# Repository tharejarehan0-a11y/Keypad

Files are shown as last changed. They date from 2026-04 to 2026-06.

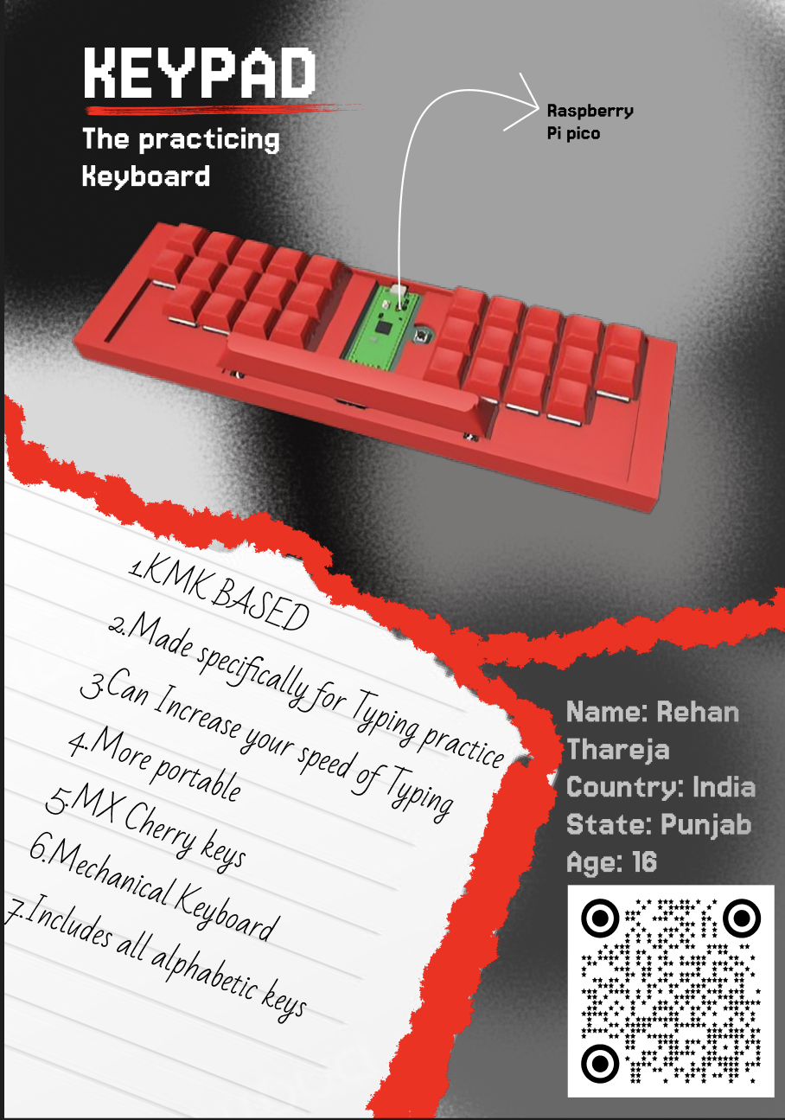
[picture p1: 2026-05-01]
zinepage.png

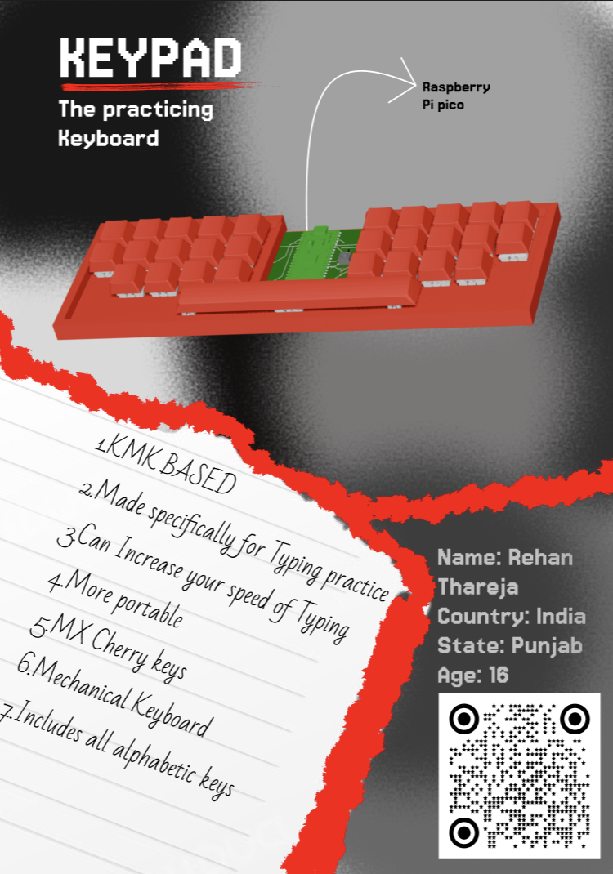
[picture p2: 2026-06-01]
Media/Zinepage.png

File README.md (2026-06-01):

# Keypad
<br>



<br>

# **Keyboard for Beginners**
(_It is Keypad a keyboard designed specifically to make learning touch typing efficient and more easy for beginners_)

<br>

<p align="center">
Screenshot 2026-06-01 at 6 14 18 PM
</p>

<br>

# **Story Behind it/Motivation**
When I started my computer journey I started learning how to do typing fast (_touch typing_). I was made to type only alphabets in the whole course some or the other way for me there was like no use of other keys similarly for many people other keys are just useless when they want to learn typing or practice it **and it is specifically designed for it**

# **Key takeaways**

1. Best for people starting touch typing
2. More portable if only learning to type
3. Mechanical keyboard with MX Cherry Keys
4. Can be customized using the firmware unlike ordinary keyboards

# **Schematics**

# Matrix
<br>
Screenshot 2026-04-22 at 7 55 31 PM
<br><br>

**These keys are layed in a matrix of rows and columns. There are 10 columns and 4 rows in the matrix. All the intersection of the rows and columns constitute a key here. The microconttroller that will be attached to these will detect low currect at the key you will press and will have already the columns and rows assigned in the firmware that let it know where the key to detect is. I have attached global labels of rows and columns which can be attached to the microcontroller and help the schematics look a lot cleaner**

<br><br>
# Keys
<br>
Screenshot 2026-04-22 at 7 51 36 PM

<br><br>
**The key composes of a keyswitch and a diode these help the microcontroller help detect the lower currect in the matrix of rows and columns**

<br><br>
# Microcontroller
<br>
Screenshot 2026-04-22 at 7 51 54 PM

<br><br>
**As a microcontroller we are using the raspberry pi pico which has 22 gpio pins the net lablels or the global net labels are attached to these pins only. The ADC_VREF pin is the analog to digital converter the 3.3v is fed into this pin but has lot of noise that is why we add a capatior of 100nF here. Then we have the 3v3 pin and the run pin . The run pin is connected to a sw_push button with one end of the push button connected to gnd and other end free and the 3v3 pin is essentially the pin that gives out the the 3v3 current it has two capacitors parallely of 100nF and 10µF to reduce the noise you can check out the design at mech_keyboard.kicad_sch**

<br><br>

# **PCB Design**
<br>
Screenshot 2026-04-22 at 8 22 37 PM
<br>

**This is the PCB Design of the keyboard having the footprints of keys of MX_Cherry , The Raspberry pi pico, resistors_smd_do35, sw_push_button and capacitors. There are also mounting holes on the pcb for the screws to fit in . We will be using the m2 screws having dimensions 2mm * 6mm and 2mm * 8mm for it . The routing follows the pattern that the capacitors , sw_push and resistors are done in the front chopper layer and the columns in the back chopper layer but there are vias also present in the pcb which make it hetrogeneous.<br><br>We have used to grind one is 19.05mm and other is 2.3813mm. the first was used for the keys which were moved by reference to it's upper right corner and the second was used for resistors which were moved without any resistors. You can check out the design in mech_Keyboard.kicad_pcb**

# **CAD**
<br>

Screenshot 2026-04-22 at 8 37 48 PM
<br>

**Go to https://www.keyboard-layout-editor.com/ to design a keyboard here we designed it complementing to our pcb and schematics paste this in the raw data tab of the site** 

<br>
<br>

```
  [{ "a": 7 }, "", "", "", "", "", { "x": 3 }, "", "", "", "", ""],
  ["", "", "", "", "", { "x": 3 }, "", "", "", "", ""],
  [{ "x": 1 }, "", "", "", "", { "x": 3 }, "", "", "", ""],
  [{ "x": 3, "w": 7 }, ""]
```

<br>

**then go to https://swillkb.com/ and paste the either the raw data of your design under the raw data tab or paste this onto the website u will get a dxf file which you can also take from the files here**

**Note: I have made some changes in the sketch according to my design you can find those sketches in 3D_Models >> DXF**

# Onshape

<br>
Screenshot 2026-05-31 at 7 18 23 PM

<br>

**Done everything in Onshape you can see all the files related to it go to 3D_Models >> STEP and if you want to see the sketches that will be in 3D_Models >> DXF and the link to onshape is https://cad.onshape.com/documents/34256bf3e585af5c7248ec84/w/d1b125939af1c93ac5709ce3/e/966044b3990b03ffc888e75f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 this you can have a look at it**

<br>

# **firmware**

<br>

Screenshot 2026-04-23 at 7 25 21 PM

<br>

**The firmware is written in Circuit python and has KMK library used to program the keyboard the keymap array is used to assign the keys to the intersection and the rows and columns are denoted by keyboard.row_pins and keyboard.col_pins and we have a name function which loads the code onto the keyboard.**

<br>

# **Components**

1. **Raspberry pi pico**
2. **MX Cherry 1.00u Keys and Keycaps**
3. **MX Cherry 7.00u Keycap and stablizer**
4. **PCB**
5. **DO-35 Resistors**
6. **SMD C_0603_1608Metric Capacitors**
7. **SW_Push Button**
8. **M2 2mm*6mm screws**

<br>

# **BOM**
**Sidenote for reviewers**
_(There is a chance that ktron.in does not accept the hcb money if it happens then i will pay my self)_

| #  | Company | Part | Quantity | Price  | Link |
|----|---|---|---|---|---|
| 1  | JLCPCB | PCB | 1 | 12.25$ | https://www.jlcpcb.com | |
| 2  | Robocraze | Raspberry Pi Pico | 1 | ₹400 | https://robocraze.com/products/raspberry-pi-pico?_pos=2&_sid=2e551ee8b&_ss=r |
| 3  | Robocraze | Male Headers (40x1 pin 2.54mm pitch) | 2 | ₹20 | https://robocraze.com/products/40x1-pin-2-54mm-pitch-male-berg-strip?_pos=11&_sid=5a10e633c&_ss=r |
| 4  | robu.in | 1N4148 Diodes | 30 | ₹180 | https://robu.in/product/1n4148-t50a-onsemi-100v-1v10ma-4ns-200ma-do-35-switching-diodes-rohs |
| 5  | KTRON | SMD 0603 Capacitors 100nF | 25 | ₹20 | https://www.ktron.in/product/100nf-50v-104-mlcc-0603/?v=2978dbfa7f71 |
| 6  | robu.in | SMD 0603 Capacitors 10uF | 5 | ₹20 | https://robu.in/product/10uf-10000nf-50v-capacitor-0603-smd-package-pack-of-5 |
| 7  | Stackskb.com | MX Cherry Keyswitches | 45 | ₹1200 | https://stackskb.com/store/akko-botany-switch-pack-of-45/ |
| 8  | Curiosity Caps | MX Cherry Keycaps | 130+  | ₹2500 | http://curiositycaps.in/products/manga-theme-cherry-pbt-keycaps?variant=50211931226393 |
| 9  | Printing Legion India (via HackClub) | Case | 1 | $2 | https://hackclub.com |
| 10 | OnlyScrews | M2x6mm Screws | 25 | ₹105 | https://onlyscrews.in/products/m2-x-6mm-phillips-round-head-laptop-screw?variant=49369266192697 |
| 11 | OnlyScrews | M2x8mm Screws | 25 | ₹110 | https://onlyscrews.in/products/m2-x-8mm-phillips-round-head-laptop-screw-1?variant=49693360423225 |
| 12 | OnlyScrews | M2 Nuts | 25 | ₹150 | https://onlyscrews.in/products/m2-nyloc-nuts-ss304-dia-2mm?variant=50164298645817 |
| 13 | Stackskb.com | Stabilizers | 4+1 | ₹1595 | https://stackskb.com/store/durock-clear-screw-in-stabilizers-v2/ |
| 14 | Robocraze | SW_Push Buttons | 25 | ₹25 | https://robocraze.com/products/4-pin-push-button-tactile-switch-12x12x15mm-pack-of-5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 |
| 15 | Shipping&Taxes | N/A | All | ₹700+39$ | N/A |

<br>

# **files**

<br>

1. **Readme.md** : explanation of all the project <br>
2. **Kicad** : All the Kicad related files <br> 
3. **Production Files** : Contains all the fabrication files used in the pcb manufacturing process <br>
4. **firmware** : This contains the firmware for the keyboard to be used <br>
5. **3D_Models*** : All the assets needed for 3D printing and all the sketches and 3D Models <br>
6. **Assets_Kicad** : All the assets needed for the schematics and pcb design including the 3d models, footprints, schematic symbols <br>
7. **Zinepage.png** : has the A5 Design for the fallout zine <br>

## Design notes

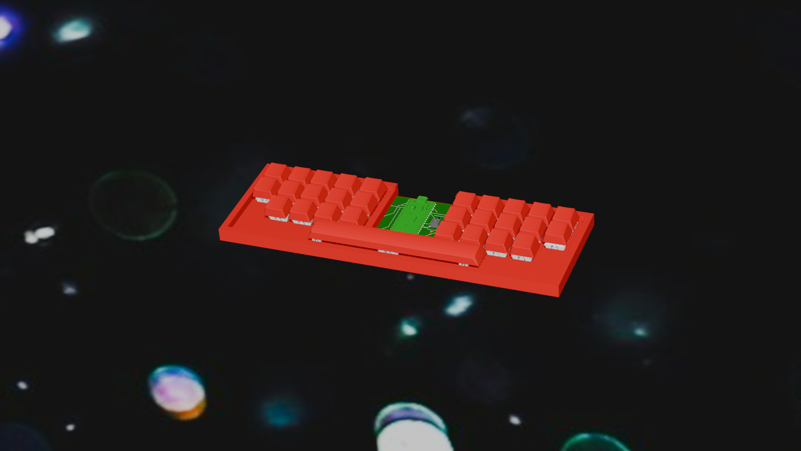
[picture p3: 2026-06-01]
Media/Untitled.png

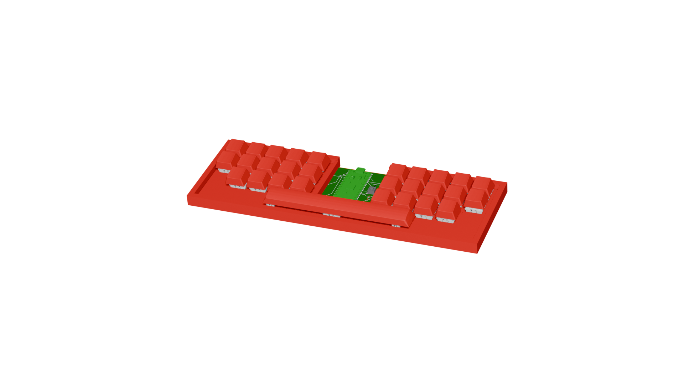
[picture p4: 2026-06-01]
Media/transparent.png

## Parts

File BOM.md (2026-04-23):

# Bill of Materials (BOM)

> Table 1 — Components for the project

| # | Company | Part | Price | Qty | Link |
|---|---|---|---:|:---:|---|
| 1 | PCBWay | PCB | $82.35 | 1 | [Order](https://www.pcbway.com/QuickOrderOnline.aspx) |
| 2 | Robocraze | Raspberry Pi Pico | ₹450.00 | 1 | [Order](https://robocraze.com/products/raspberry-pi-pico?_pos=2&_sid=2e551ee8b&_ss=r) |
| 3 | Robocraze | Male Headers (40×1 pin, 2.54mm pitch) | ₹12.00 | 2 | [Order](https://robocraze.com/products/40x1-pin-2-54mm-pitch-male-berg-strip?_pos=11&_sid=5a10e633c&_ss=r) |
| 4 | robu.in | 1N4148 Diodes | ₹180.00 | 30 | [Order](https://robu.in/product/1n4148-t50a-onsemi-100v-1v10ma-4ns-200ma-do-35-switching-diodes-rohs) |
| 5 | KTRON | SMD 0603 Capacitors 100nF | ₹100.00 | 25 | [Order](https://www.ktron.in/product/100nf-50v-104-mlcc-0603/?v=2978dbfa7f71) |
| 6 | robu.in | SMD 0603 Capacitors 10µF | ₹4.00 | 1 | [Order](https://robu.in/product/10uf-10000nf-50v-capacitor-0603-smd-package-pack-of-5) |
| 7 | Stackskb.com | MX Cherry Keyswitches (Akko Botany) | ₹1,200.00 | 45 | [Order](https://stackskb.com/store/akko-botany-switch-pack-of-45/) |
| 8 | Curiosity Caps | MX Cherry Keycaps (Manga Theme PBT) | ₹2,500.00 | 130 | [Order](http://curiositycaps.in/products/manga-theme-cherry-pbt-keycaps?variant=50211931226393) |
| 9 | Printing Legion India *(via HackClub)* | Case | $1.30 | 1 | [@speedhawks on Hackclub](https://hackclub.com) |
| 10 | OnlyScrews | M2*6mm screws | ₹105 | 25 | [Order](https://onlyscrews.in/products/m2-x-6mm-phillips-round-head-laptop-screw?variant=49369266192697) |
| 11 | OnlyScrews | M2*8mm screws | ₹110 | 25 | [Order](https://onlyscrews.in/products/m2-x-8mm-phillips-round-head-laptop-screw-1?variant=49693360423225) |
| 12 | OnlyScrews | M2 nuts | ₹105 | 25 | [Order](https://onlyscrews.in/products/m2-nyloc-nuts-ss304-dia-2mm?variant=50164298645817) |
| 13 | OnlyScrews | Shipping & Tax | ₹126 | N/A | [Order](https://onlyscrews.in/)

---

> **Note:** Prices marked in ₹ are in Indian Rupees; prices marked in $ are in US Dollars.

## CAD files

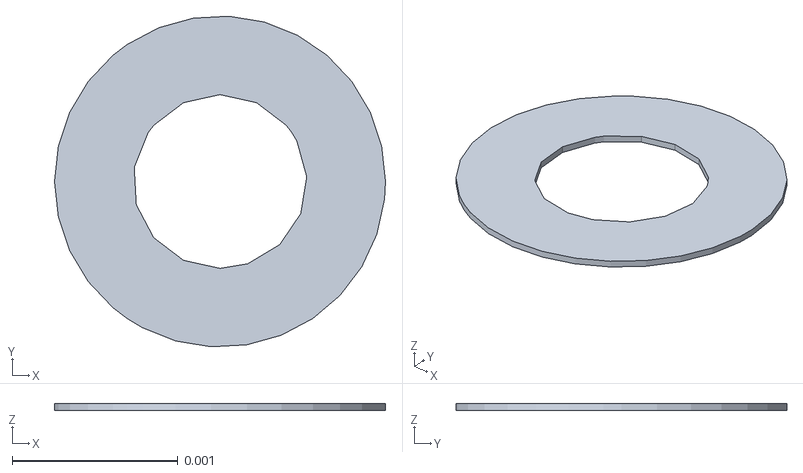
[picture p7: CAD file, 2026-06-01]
3D_Models/STL/assembly/Assembly_Components/Assembly 1 - mech_Keyboard_pad (144).stl
0.002 x 0.002 x 4e-05

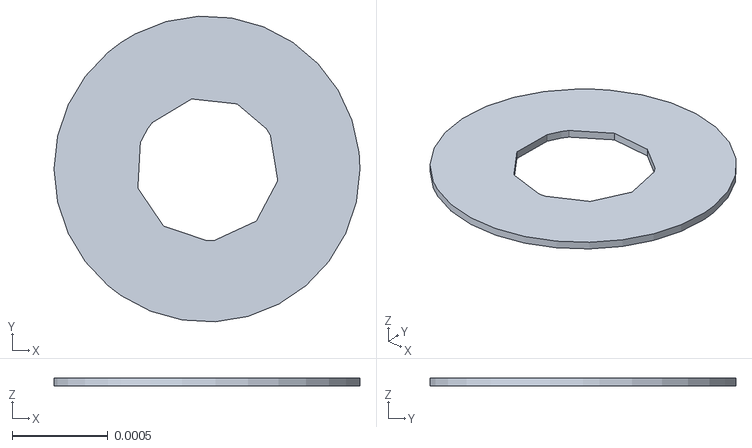
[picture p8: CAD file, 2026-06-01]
3D_Models/STL/assembly/Assembly_Components/Assembly 1 - mech_Keyboard_pad (264).stl
0.0016 x 0.0016 x 4e-05

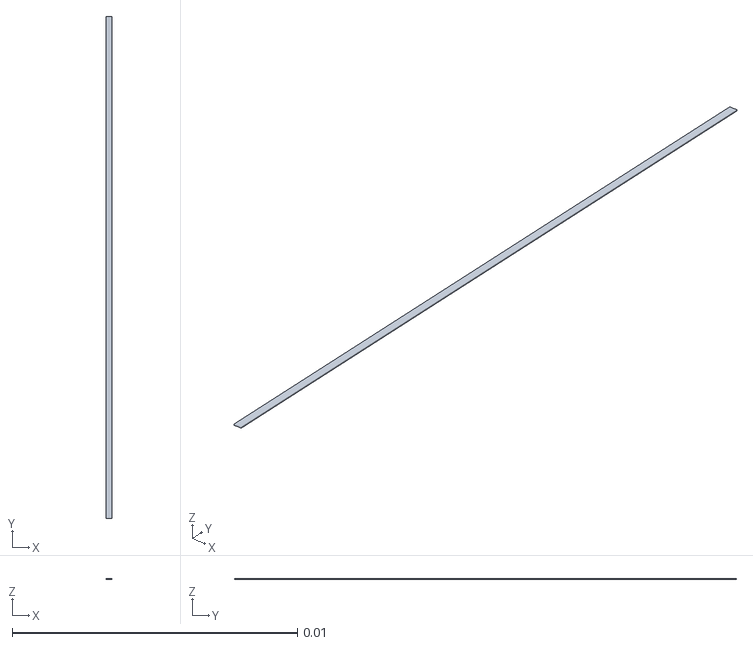
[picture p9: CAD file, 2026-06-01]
3D_Models/STL/assembly/Assembly_Components/Assembly 1 - mech_Keyboard_copper (69).stl
0.000198 x 0.0176 x 3.5e-05

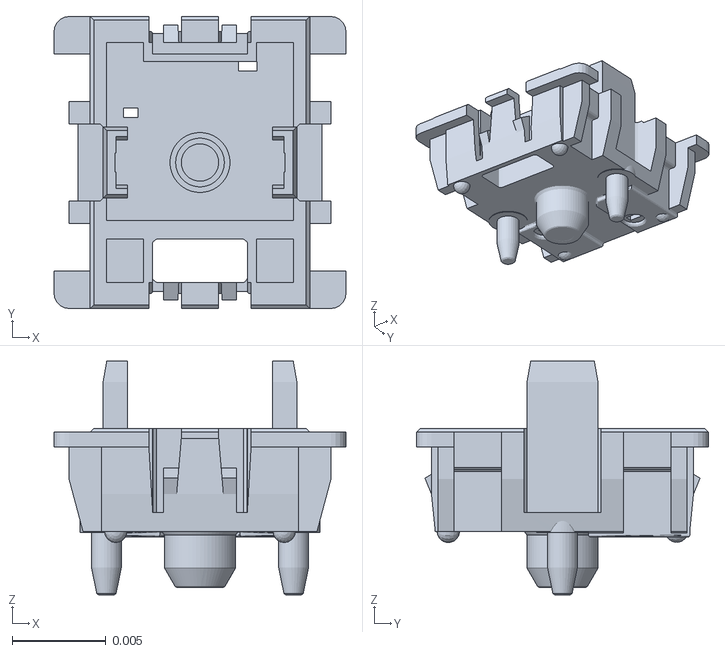
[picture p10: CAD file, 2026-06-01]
3D_Models/STL/assembly/Assembly_Components/Assembly 1 - MX_PCB_28.stl
0.0156 x 0.0156 x 0.0125

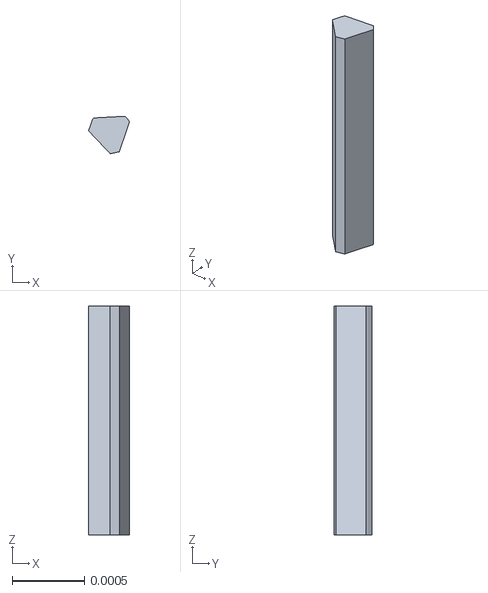
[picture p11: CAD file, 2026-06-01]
3D_Models/STL/assembly/Assembly_Components/Assembly 1 - mech_Keyboard_via (23).stl
0.000282 x 0.000259 x 0.00158

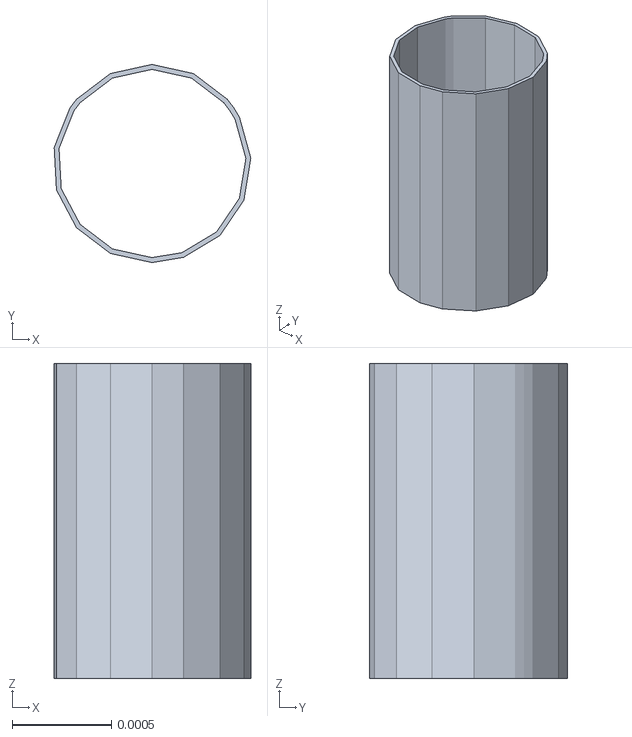
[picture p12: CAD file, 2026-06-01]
3D_Models/STL/assembly/Assembly_Components/Assembly 1 - mech_Keyboard_pad (78).stl
0.000993 x 0.001 x 0.00159

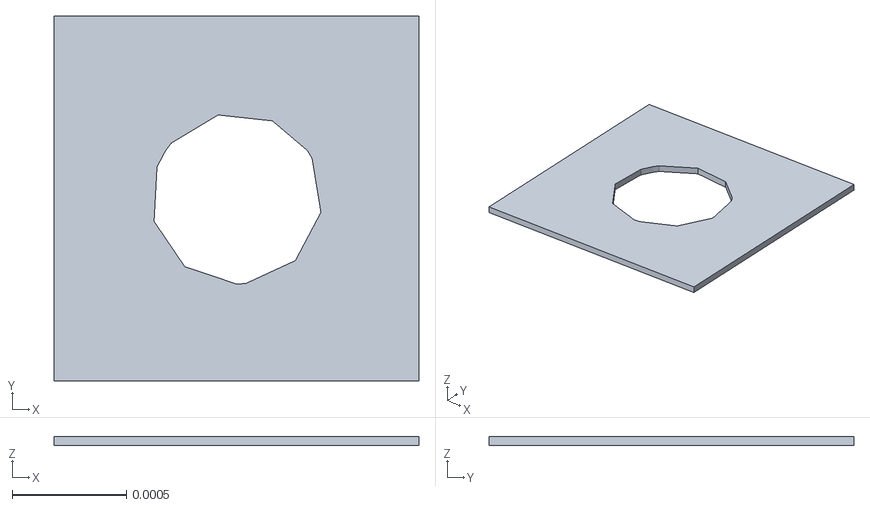
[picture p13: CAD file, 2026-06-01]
3D_Models/STL/assembly/Assembly_Components/Assembly 1 - mech_Keyboard_pad (328).stl
0.0016 x 0.0016 x 4e-05

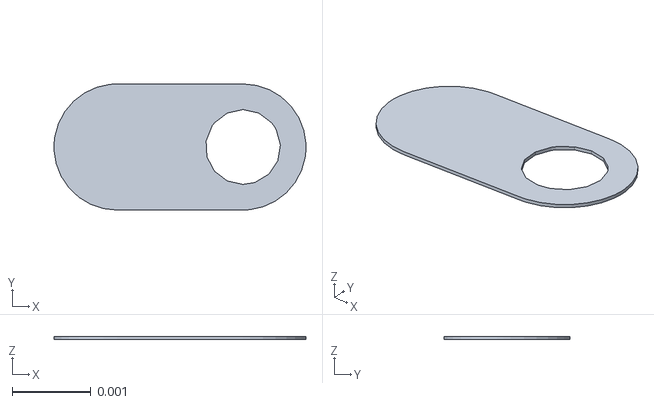
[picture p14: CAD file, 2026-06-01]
3D_Models/STL/assembly/Assembly_Components/Assembly 1 - mech_Keyboard_pad (418).stl
0.0032 x 0.0016 x 4e-05

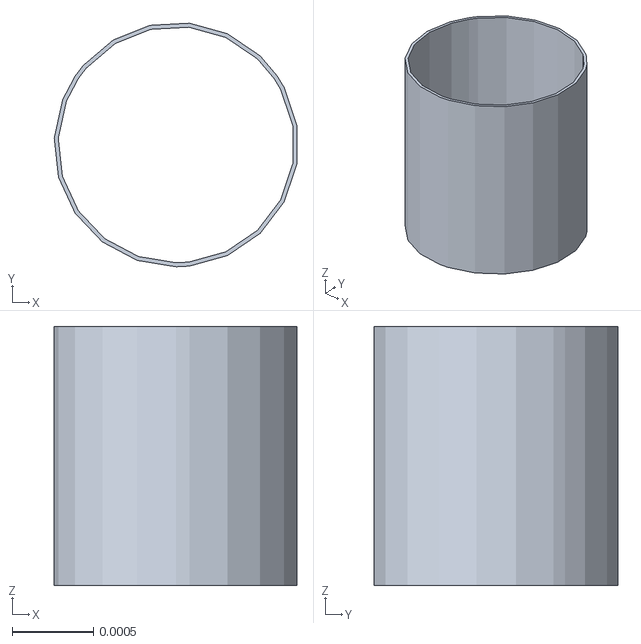
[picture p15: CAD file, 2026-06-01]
3D_Models/STL/assembly/Assembly_Components/Assembly 1 - mech_Keyboard_pad (217).stl
0.00149 x 0.0015 x 0.00159

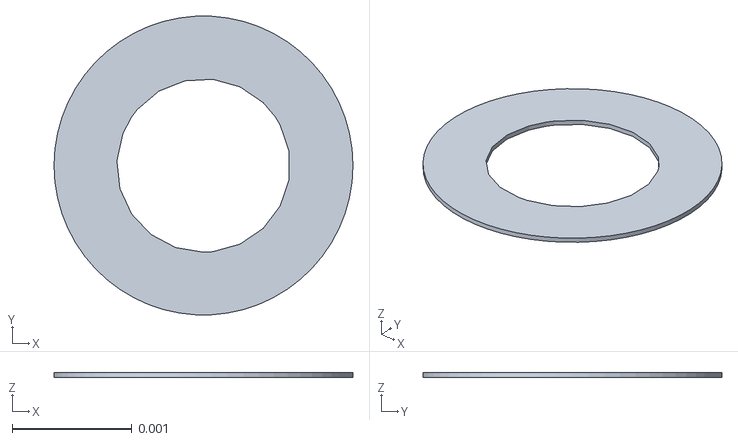
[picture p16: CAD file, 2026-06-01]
3D_Models/STL/assembly/Assembly_Components/Assembly 1 - mech_Keyboard_pad (147).stl
0.0025 x 0.0025 x 4e-05

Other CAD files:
3D_Models/STL/assembly/Assembly_Components/Assembly 1 - mech_Keyboard_pad (337).stl
3D_Models/STL/assembly/Assembly_Components/Assembly 1 - mech_Keyboard_via (24).stl
3D_Models/STL/assembly/Assembly_Components/Assembly 1 - mech_Keyboard_copper (25).stl
3D_Models/STL/assembly/Assembly_Components/Assembly 1 - mech_Keyboard_pad (60).stl
3D_Models/STL/assembly/Assembly_Components/Assembly 1 - mech_Keyboard_pad (496).stl
3D_Models/STL/assembly/Assembly_Components/Assembly 1 - mech_Keyboard_pad (363).stl
3D_Models/STL/assembly/Assembly_Components/Assembly 1 - mech_Keyboard_pad (62).stl
3D_Models/STL/assembly/Assembly_Components/Assembly 1 - mech_Keyboard_pad (204).stl
3D_Models/DXF (Sketches)/FirstSketch.dxf
3D_Models/DXF (Sketches)/SecondSketch.dxf
3D_Models/STEP/Case/Lowercase.step
3D_Models/STEP/Case/Uppercase.step
3D_Models/STEP/Keycaps/Cherry MX keycaps .step
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

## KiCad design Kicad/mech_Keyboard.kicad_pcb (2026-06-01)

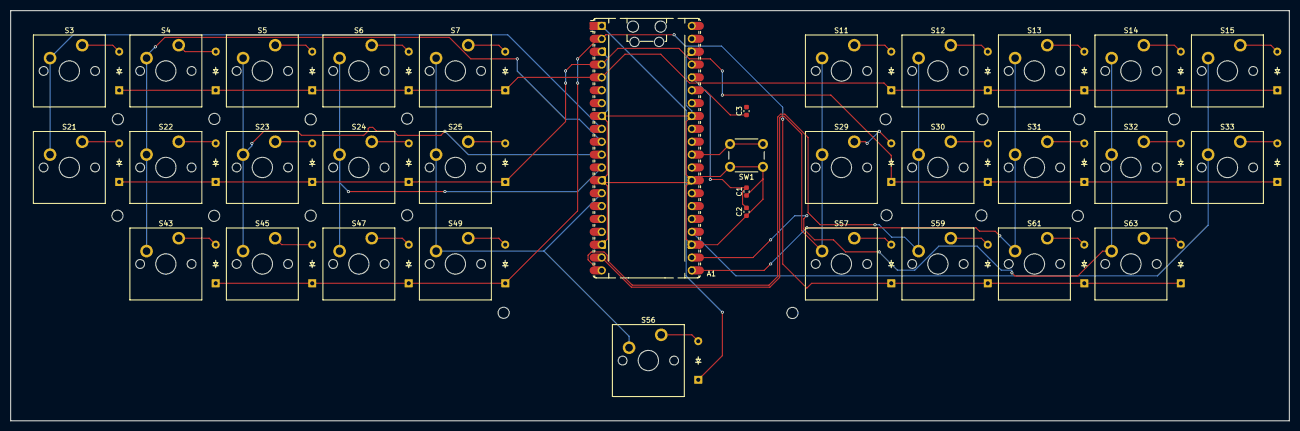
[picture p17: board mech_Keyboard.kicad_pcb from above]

Board: 2 copper layers, 252.4 x 81.0 mm, 63 parts (0 on the bottom side), 47 nets.

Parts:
A1: RaspberryPi_Pico; RaspberryPi_Pico_Common_Unspecified
C1, C3: 100nF; C_0603_1608Metric
C2: 10µF; C_0603_1608Metric
D3, D4, D5, D6, D7, D11, D12, D13, D14, D15, D21, D22, D23, D24, D25, D29, D30, D31, D32, D33, D43, D45, D47, D49, D56, D57, D59, D61, D63: Diode_DO-35
S3, S4, S5, S6, S7, S11, S12, S13, S14, S15, S21, S22, S23, S24, S25, S29, S30, S31, S32, S33, S43, S45, S47, S49, S57, S59, S61, S63: MX_PCB_1.00u
S56: MX_PCB_7.00u
SW1: SW_Push; SW_PUSH_6mm_H5mm

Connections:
COLUMN3: A1.9 (GPIO6), S3.1, S21.1
COLUMN4: A1.10 (GPIO7), S4.1, S22.1, S43.1
COLUMN5: A1.11 (GPIO8), S5.1, S23.1, S45.1
COLUMN6: A1.12 (GPIO9), S6.1, S24.1, S47.1
COLUMN7: A1.14 (GPIO10), S7.1, S25.1, S49.1, S56.1
COLUMN11: A1.19 (GPIO14), S11.1, S29.1, S57.1
COLUMN12: A1.20 (GPIO15), S12.1, S30.1, S59.1
COLUMN13: A1.21 (GPIO16), S13.1, S31.1, S61.1
COLUMN14: A1.22 (GPIO17), S14.1, S32.1, S63.1
COLUMN15: A1.24 (GPIO18), S15.1, S33.1
GND: A1.3 (GND), A1.8 (GND), A1.13 (GND), A1.18 (GND), A1.23 (GND), A1.28 (GND), A1.33 (AGND), A1.38 (GND), C1.1, C2.1, SW1.1
unnamed: A1.36 (3V3), C1.2, C2.2
unnamed: A1.35 (ADC_VREF), C3.1
unnamed: A1.30 (RUN), SW1.2
unnamed: D3.2 (A), S3.2
unnamed: D4.2 (A), S4.2
unnamed: D5.2 (A), S5.2
unnamed: D6.2 (A), S6.2
unnamed: D7.2 (A), S7.2
unnamed: D11.2 (A), S11.2
unnamed: D12.2 (A), S12.2
unnamed: D13.2 (A), S13.2
unnamed: D14.2 (A), S14.2
unnamed: D15.2 (A), S15.2
unnamed: D21.2 (A), S21.2
unnamed: D22.2 (A), S22.2
unnamed: D23.2 (A), S23.2
unnamed: D24.2 (A), S24.2
unnamed: D25.2 (A), S25.2
unnamed: D29.2 (A), S29.2
unnamed: D30.2 (A), S30.2
unnamed: D31.2 (A), S31.2
unnamed: D32.2 (A), S32.2
unnamed: D33.2 (A), S33.2
unnamed: D43.2 (A), S43.2
unnamed: D45.2 (A), S45.2
unnamed: D47.2 (A), S47.2
unnamed: D49.2 (A), S49.2
unnamed: D56.2 (A), S56.2
unnamed: D57.2 (A), S57.2
unnamed: D59.2 (A), S59.2
unnamed: D61.2 (A), S61.2
unnamed: D63.2 (A), S63.2
ROW1: A1.1 (GPIO0), D56.1 (K)
ROW2: A1.2 (GPIO1), D43.1 (K), D45.1 (K), D47.1 (K), D49.1 (K), D57.1 (K), D59.1 (K), D61.1 (K), D63.1 (K)
ROW3: A1.4 (GPIO2), D21.1 (K), D22.1 (K), D23.1 (K), D24.1 (K), D25.1 (K), D29.1 (K), D30.1 (K), D31.1 (K), D32.1 (K), D33.1 (K)
ROW4: A1.5 (GPIO3), D3.1 (K), D4.1 (K), D5.1 (K), D6.1 (K), D7.1 (K), D11.1 (K), D12.1 (K), D13.1 (K), D14.1 (K), D15.1 (K)

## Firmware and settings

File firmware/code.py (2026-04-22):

import board
from kmk.kmk_keyboard import KMKKeyboard
from kmk.keys import KC
from kmk.scanners import DiodeOrientation

keyboard = KMKKeyboard()
keyboard.col_pins = (board.GP6, board.GP7, board.GP8, board.GP9, board.GP10, board.GP14, board.GP15, board.GP16, board.GP17, board.GP18)
keyboard.row_pins = (board.GP0, board.GP1, board.GP2, board.GP3)
keyboard.diode_orientation = DiodeOrientation.COL2ROW
keyboard.keymap = [
                   [KC.Q, KC.W, KC.E, KC.R, KC.T, KC.Y, KC.U, KC.I, KC.O, KC.P],
                   [KC.A, KC.S, KC.D, KC.F, KC.G, KC.H, KC.J, KC.K, KC.L, KC.SCLN],
                   [KC.NO, KC.Z, KC.X, KC.C, KC.V, KC.B, KC.N, KC.M, KC.BSPC, KC.NO],
                   [KC.NO, KC.NO, KC.NO, KC.NO, KC.SPACE, KC.NO, KC.NO, KC.NO, KC.NO, KC.NO]
                   ]

if __name__ == '__main__':
    keyboard.go()

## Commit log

2026-04-22 Intialization
    Added all the files to the repo
    [mech_Keyboard.kicad_pcb, mech_Keyboard.kicad_sch]
2026-04-23 assets added
    [Keycap_CherryMX.stl, case.dxf.stl, lowercase.stl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]
2026-04-23 finalized changes
    [pcb.stl]
2026-04-23 Add gerber archive and BOM; update PCB files
    Add an Archive/ folder containing generated Gerber (F/Cu, mask, paste, silkscreen), edge cuts, and drill files plus Archive.zip and .DS_Store; add BOM.csv. Update mech_Keyboard.kicad_pcb and mech_Key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
    [BOM.csv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]
2026-04-23 fixed bom
    [BOM.csv, BOM_corrected.csv]
2026-04-23 Add new items to BOM with pricing and links
2026-04-23 Update quantities for OnlyScrews items in BOM
2026-04-23 Refactor BOM.csv with new header format
    Updated BOM.csv to a new format with headers and corrected links.
    [BOM.csv]
2026-04-23 modified bom
    [BOM.csv]
2026-04-25 Change PCB price and source in BOM.csv
    Updated PCB price and supplier link in BOM.
    [BOM.csv]
2026-04-25 Change PCB price in BOM.csv
    Updated the price of PCB from $27 to $30-80.
    [BOM.csv]
2026-04-25 Remove price and quantity from BOM.csv
    Removed price and quantity information from BOM.csv entries.
    [BOM.csv]
2026-04-28 Revise BOM with quantities and updated prices
    Updated BOM.csv with quantities and prices in INR.
    [BOM.csv]
2026-04-28 Remove shipping note from BOM.csv
    Removed the line indicating that shipping is not included.
    [BOM.csv]
2026-04-28 Change BOM file from BOM.md to BOM.csv
    Updated BOM file reference from BOM.md to BOM.csv and added note about shipping.
2026-04-28 Add shipping and taxes entry to BOM.csv
    [BOM.csv]
2026-05-01 Revise Kicad and assets section in README
    Updated file names and descriptions for clarity.
2026-05-01 Add BOM section with components and links
2026-05-01 bom.csv deleted
    [BOM.csv]
2026-05-01 Revise asset names and BOM details in README
    Updated asset names and added new components to the BOM.
2026-05-03 Update PCB supplier and shipping cost in README
2026-05-03 Fix JLCPCB link in BOM.csv
    Updated the link for JLCPCB in BOM.csv.
    [BOM.csv]
2026-06-01 did some stuff with organising
    [Assembly 1 - 1x1 R1 v23.stl, Assembly 1 - C_0603_1608Metric.stl, Assembly 1 - C_0603_1608Metric_1.stl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]
